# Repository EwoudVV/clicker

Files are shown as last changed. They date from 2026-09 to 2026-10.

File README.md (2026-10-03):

# Clicker

A 2-switch wireless macropad.

This project is 2 pcbs. One is a reciever, which you plug into your computer, and the other is a remote, or transmitter, with the buttons. The reciever acts like a keyboard, so no drivers need to be installed on the computer.



Remote: 
Receiver: 

Reciever pcb:
 - 2 layer
 - esp32 s3
 - has a usb-c port for computer
 - an led that blinks when something is being sent

Remote pcb:
 - same esp32 s3
 - small battery
 - 2 switches (khalih choc v1 smd)
 - 2 layer
 - 2 side assembly
 - usb-c port for charging

Roadmap:
 - finish up, make production files
 - submit!

Completed:
 - Find and place symbols
 - wire up both schematics
 - find specific part numbers and footprints for everything
 - route the pcbs

Designed by EVV

*Made for Hack Club Half Life*

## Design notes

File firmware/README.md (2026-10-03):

# Clicker firmware

The remote sends its two button states over ESP-NOW. The receiver turns them into USB keyboard reports. Button 1 is left arrow and button 2 is right arrow by default, for slides.

Both sketches compile with Espressif's Arduino core 3.3.12. The boards have not been built or tested yet.

## boards and pins

| | remote | receiver |
|---|---|---|
| module | ESP32-C3-WROOM-02-N4 | ESP32-S3-WROOM-1-N4 |
| button 1 | GPIO5, active low | — |
| button 2 | GPIO6, active low | — |
| LED | GPIO7, active high | GPIO4, active high |
| USB D-/D+ | GPIO18 / GPIO19 | GPIO19 / GPIO20 |
| debug RX / TX | GPIO20 / GPIO21 | GPIO44 / GPIO43 |

These are GPIO numbers, not the module's physical pad numbers. They come from the schematics. The battery divider is on remote GPIO4; this version does not use it for battery protection or sleep.

## build

Install Arduino CLI and the official ESP32 core:

```sh
arduino-cli core update-index --additional-urls https://espressif.github.io/arduino-esp32/package_esp32_index.json
arduino-cli core install esp32:esp32@3.3.12 --additional-urls https://espressif.github.io/arduino-esp32/package_esp32_index.json
```

From the repo root:

```sh
./firmware/test.sh
./firmware/build.sh
```

`test.sh` runs the portable button/packet state tests on the computer, with address and undefined-behavior sanitizers. It does not emulate Wi-Fi, USB, flash storage, or the electronics. `build.sh` compiles both sketches and saves compiler results under `verification/2026-10-03/`. Builds go in the ignored `work/` folder.

In Arduino IDE, add `firmware/libraries` as a sketchbook library location or install its Clicker folder as a library. Select **ESP32C3 Dev Module** for the remote and **ESP32S3 Dev Module** for the receiver, with 4 MB flash, no PSRAM, and USB CDC on boot enabled. The receiver needs **USB-OTG (TinyUSB)** USB mode. Hardware CDC/JTAG mode cannot provide the keyboard interface.

For the first flash, hold BOOT, tap RESET, then release BOOT and select the board's serial port. Both boards have USB wired to the native pins. If that does not enumerate, use the debug header with a 3.3 V logic USB-UART adapter. The header is GND, RX, TX; it has no power pin. UART lines cross: adapter TX to board RX and adapter RX to board TX. Power the board through USB.

From the `firmware` folder, replacing `<port>` with the real port:

```sh
arduino-cli upload --fqbn esp32:esp32:esp32c3:CDCOnBoot=cdc,FlashSize=4M --input-dir ../work/build-remote --port '<port>' remote
arduino-cli upload --fqbn esp32:esp32:esp32s3:USBMode=default,CDCOnBoot=cdc,FlashSize=4M,PSRAM=disabled --input-dir ../work/build-receiver --port '<port>' receiver
```

These upload steps are instructions for later; no board has been flashed.

## pairing

Each board has a USB serial configuration console at 115200 baud. Send commands with a newline. Nothing transmits keyboard data until the pair is configured.

1. Run `status` on each board and note its MAC address.
2. Generate one random 16-byte link key on your computer:

   ```sh
   python3 -c 'import secrets; print(secrets.token_hex(16))'
   ```

3. On the remote, send `pair <receiver-MAC> <key>`.
4. On the receiver, send `pair <remote-MAC> <same-key>`.

For example, the command shape is `pair AA:BB:CC:DD:EE:02 <32 hex digits>`; use the actual other board's address and the generated key. Pairing survives restarts. `unpair` removes it. `status` shows addresses and mappings but does not print the key.

Both devices use Wi-Fi channel 1 and encrypted unicast ESP-NOW. No router or Wi-Fi password is needed. The receiver also checks that packets came from the configured remote address. If changing the radio channel in the source, rebuild both boards.

## remapping

Send these commands to the receiver's USB serial console. They save in flash immediately, with no new firmware upload needed:

```text
map 1 left
map 2 right
status
```

For page up/down:

```text
map 1 pageup
map 2 pagedown
```

Other names: `up`, `down`, `space`, `enter`, `escape`, `home`, `end`, `a` through `z`, or `disabled`. For other keys, use a USB HID keyboard usage number, such as `0x3A` for F1. These are HID usages, not ASCII or Arduino `KEY_*` values. Supported numeric usages are 0x04 through 0x65.

An optional modifier byte supports shortcuts:

```text
map 1 a 0x08
map 2 b 0x02
```

That maps button 1 to Command+A on macOS, and button 2 to Shift+B. Modifier bits are left Ctrl 0x01, Shift 0x02, Alt/Option 0x04, GUI/Command 0x08; right-side equivalents are 0x10, 0x20, 0x40, 0x80. Add the bits for combinations. Media consumer-control usages and multi-step macros are not implemented.

Open the serial console again and use `status` if the boot message was missed. On macOS a terminal console can be opened with `screen <serial-port> 115200`; leave it with Ctrl+A, then K. Close the console before uploading firmware.

## behavior

- Button debounce is 15 ms.
- Full state packets go out on changes and every 50 ms. A later packet can recover a dropped release.
- The receiver drops duplicate and older sequence numbers within a remote boot session.
- After 300 ms without a valid new packet, the receiver releases all keys.
- Both pressed buttons appear together in one HID report. Identical mappings appear once.
- Failed USB reports are retried; a USB reconnect sends the current state again.
- The remote LED indicates a queued send, not a delivery acknowledgement. The receiver LED flashes on accepted packets.

This version keeps the remote's radio awake. Battery runtime and low-power sleep need measurements before choosing a power-saving strategy.

## when the boards arrive

- Check assembly, connector polarity, and resistance between power and ground before powering.
- Start with current-limited USB power and measure both 3.3 V rails. Address the open power issues in `docs/hardware-review-2026-10-03.md` before connecting a battery.
- Flash each board, open its console, and check `status`.
- Pair the devices. Verify the receiver appears as a keyboard and serial device.
- Test short presses, holds, and both buttons in a text editor, then in slides.
- Hold a button and turn the remote off. Confirm the computer releases the key within about 300 ms.
- Change mappings, restart both boards, and verify the saved settings.
- Disconnect/reconnect the receiver USB while a button is held. Verify there are no stuck keys.
- Measure battery supply sag and current during transmission. Check charging and charge termination with the selected battery and both switch positions.
- Check range and latency with the final case and battery in place.

References: [Arduino ESP-NOW](https://docs.espressif.com/projects/arduino-esp32/en/latest/api/espnow.html), [Arduino USB](https://docs.espressif.com/projects/arduino-esp32/en/latest/api/usb.html), [Espressif USB keyboard source](https://github.com/espressif/arduino-esp32/blob/3.3.12/libraries/USB/src/USBHIDKeyboard.cpp).

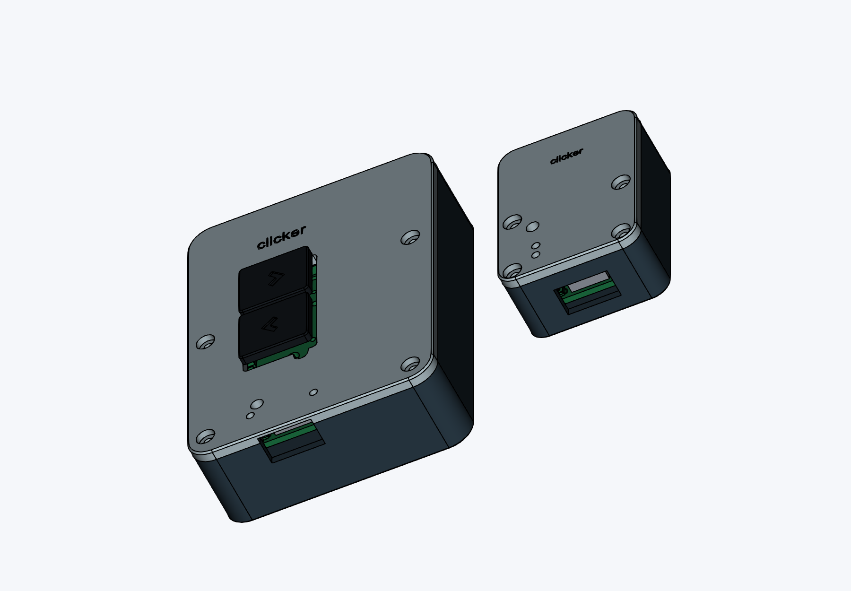
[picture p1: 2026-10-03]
enclosures/preview.png

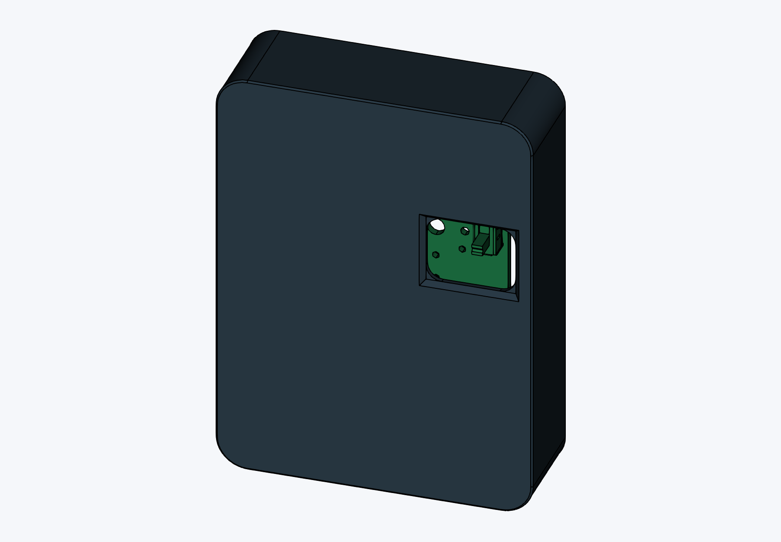
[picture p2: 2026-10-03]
enclosures/remote-underside.png

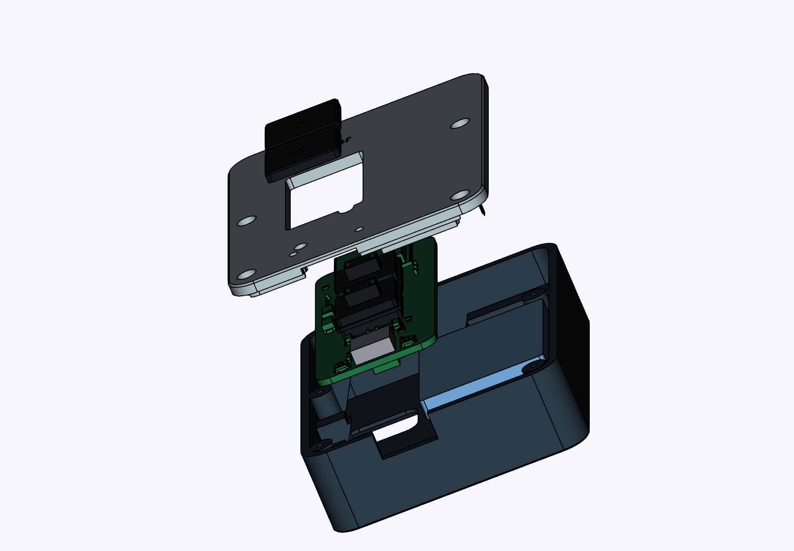
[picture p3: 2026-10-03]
enclosures/remote-exploded.png

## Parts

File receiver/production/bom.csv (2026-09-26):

Item # | Designator | Qty | Manufacturer | Mfg Part # | Description | Package | Type
1 | U1 | 1 | Espressif | ESP32-S3-WROOM-1-N4 | WiFi+BLE5 module, 4MB flash, PCB antenna, native USB | SMD module | Module
2 | U2 | 1 | Diodes Inc | AP2112K-3.3TRG1 | 600mA low-dropout regulator, 3.3V fixed | SOT-23-5 | IC
3 | J1 | 1 | HRO | TYPE-C-31-M-12 | USB Type-C receptacle, 16P, USB2.0+PD | SMD | Connector
4 | HDR1 | 1 | Generic | 1x03 2.54mm pin header | Pin header 1x3, 2.54mm pitch, vertical | THT | Connector
5 | SW_BOOT, SW_RST | 2 | Omron | B3U-1000P | Tactile switch, top actuated | SMD | Switch
6 | D1 | 1 | Everlight | 19-213/R6C-AL1M2VY/3T | Red 0603 LED | 0603 | LED
7 | R_ACT | 1 | UNI-ROYAL | 0603WAF1001T5E | 1k ohm 1% 1/10W | 0603 | Resistor
8 | R_CC1, R_CC2 | 2 | UNI-ROYAL | 0603WAF5101T5E | 5.1k ohm 1% 1/10W | 0603 | Resistor
9 | R_EN | 1 | UNI-ROYAL | 0603WAF1002T5E | 10k ohm 1% 1/10W | 0603 | Resistor
10 | C1 | 1 | Samsung | CL10B104KB8NNNC | 100nF 50V X7R ceramic | 0603 | Capacitor
11 | C2 | 1 | Samsung | CL10A106MQ8NNNC | 10uF 6.3V X5R ceramic | 0603 | Capacitor
12 | C3 | 1 | Samsung | CL10B105KO8NNNC | 1uF 25V X7R ceramic | 0603 | Capacitor

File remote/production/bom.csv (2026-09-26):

Item # | Designator | Qty | Manufacturer | Mfg Part # | Description | Package | Type
1 | U1 | 1 | Espressif | ESP32-C3-WROOM-02-N4 | WiFi+BLE5 module, RISC-V, 4MB flash, PCB antenna | SMD module | Module
2 | U2 | 1 | Microchip | MCP73831T-2ATI/OT | Li-Ion charge management controller, 4.2V, 500mA | SOT-23-5 | IC
3 | U3 | 1 | Diodes Inc | AP2112K-3.3TRG1 | 600mA low-dropout regulator, 3.3V fixed | SOT-23-5 | IC
4 | J1 | 1 | HRO | TYPE-C-31-M-12 | USB Type-C receptacle, 16P, USB2.0+PD | SMD | Connector
5 | J_BAT | 1 | JST | B2B-PH-K-S | PH 2.0mm 2-pin vertical header | THT | Connector
6 | HDR1 | 1 | Generic | 1x03 2.54mm pin header | Pin header 1x3, 2.54mm pitch, vertical | THT | Connector
7 | SW1, SW2 | 2 | Kailh | CPG135001D01 | Choc V1 low-profile mechanical switch, linear red | THT | Switch
8 | SW_BOOT, SW_RST | 2 | Omron | B3U-1000P | Tactile switch, top actuated | SMD | Switch
9 | SW_PWR | 1 | C&K | OS102011MS2Q | Miniature SPDT slide switch | THT | Switch
10 | D_CHG, D_STAT | 2 | Everlight | 19-213/R6C-AL1M2VY/3T | Red 0603 LED | 0603 | LED
11 | D_VBAT, D_VBUS | 2 | MDD | SS14 | 1A 40V Schottky rectifier | SMA | Diode
12 | R_CC1, R_CC2 | 2 | UNI-ROYAL | 0603WAF5101T5E | 5.1k ohm 1% 1/10W | 0603 | Resistor
13 | R_EN | 1 | UNI-ROYAL | 0603WAF1002T5E | 10k ohm 1% 1/10W | 0603 | Resistor
14 | R_UP, R_DN | 2 | UNI-ROYAL | 0603WAF1003T5E | 100k ohm 1% 1/10W | 0603 | Resistor
15 | R_PROG | 1 | UNI-ROYAL | 0603WAF2001T5E | 2k ohm 1% 1/10W | 0603 | Resistor
16 | R_CHG, R_STAT | 2 | UNI-ROYAL | 0603WAF1001T5E | 1k ohm 1% 1/10W | 0603 | Resistor
17 | C1 | 1 | Samsung | CL10B104KB8NNNC | 100nF 50V X7R ceramic | 0603 | Capacitor
18 | C2 | 1 | Samsung | CL10A106MQ8NNNC | 10uF 6.3V X5R ceramic | 0603 | Capacitor
19 | C3 | 1 | Samsung | CL10B105KO8NNNC | 1uF 25V X7R ceramic | 0603 | Capacitor

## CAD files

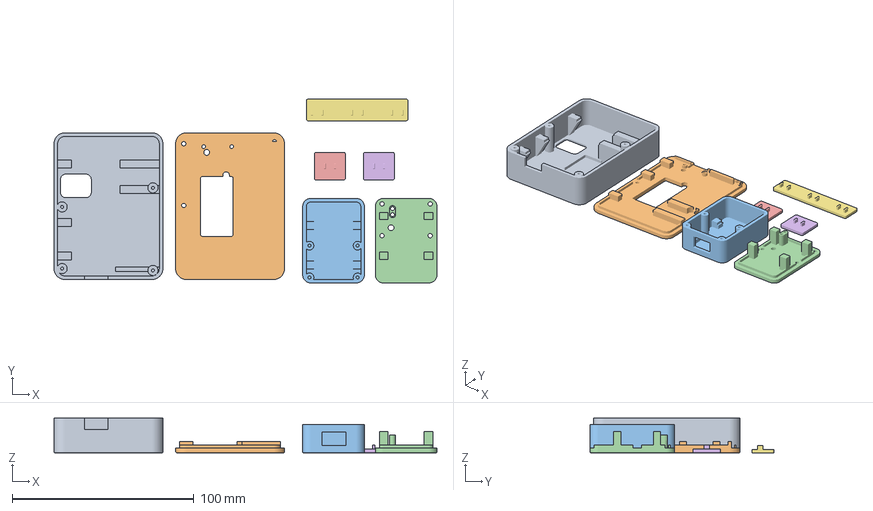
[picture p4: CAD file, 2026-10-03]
enclosures/clicker-print-plate.3mf
211.0 x 101.3 x 19.1 mm
remote_base
remote_lid
receiver_base
receiver_lid
keycap_previous
keycap_next
stem_fit_coupon

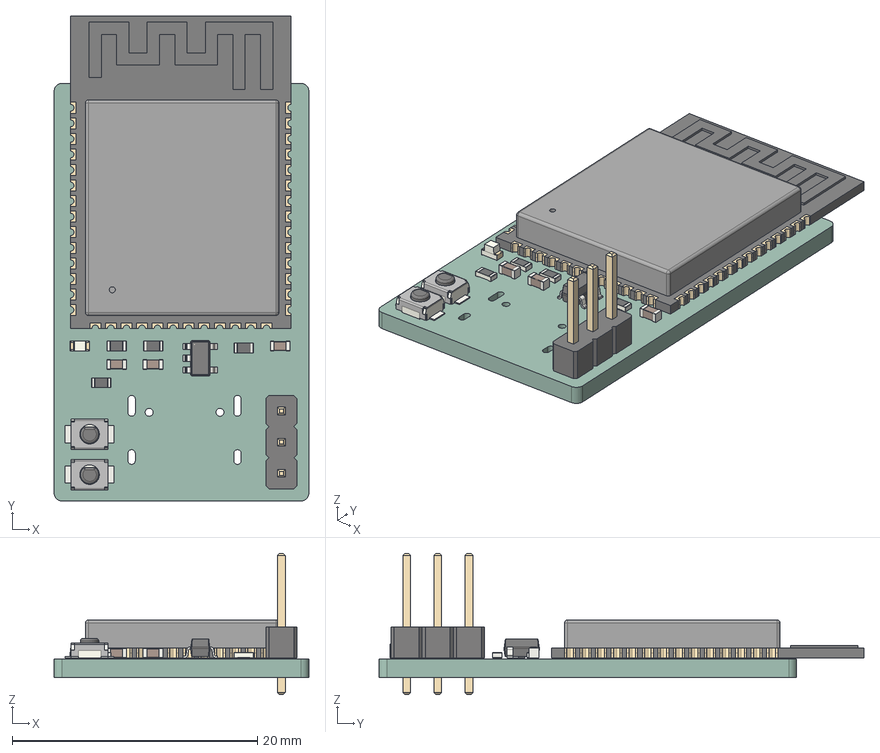
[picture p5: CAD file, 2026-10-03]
enclosures/reference/receiver.step
20.8 x 39.6 x 11.5 mm
R_0603_1608Metric x 4
C_0603_1608Metric x 3
SW_SPST_B3U-1000P x 2
PinHeader_1x03_P254mm_Vertical
LED_0603_1608Metric
ESP32-S3-WROOM-1
SOT-23-5
receiver_PCB

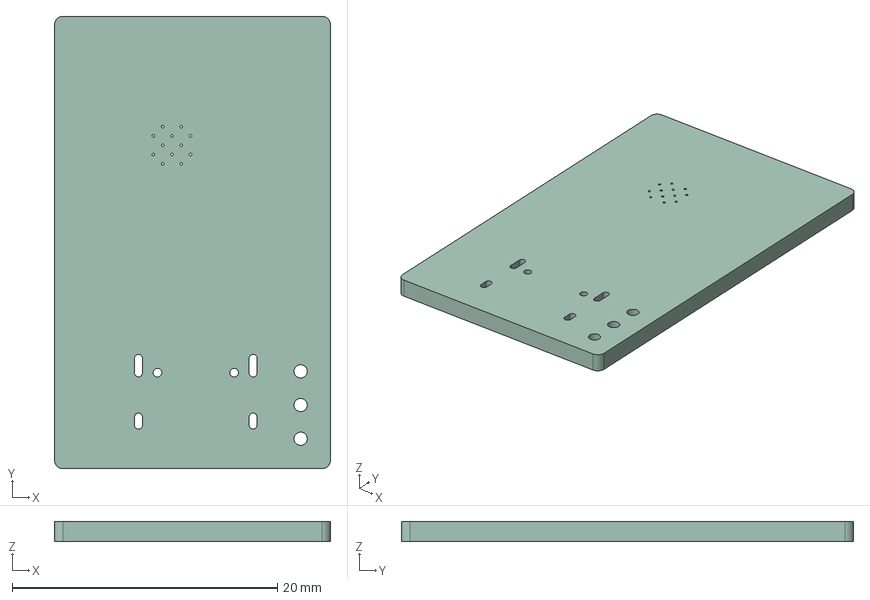
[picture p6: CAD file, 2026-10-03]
enclosures/reference/receiver-board.step
20.8 x 34.1 x 1.51 mm

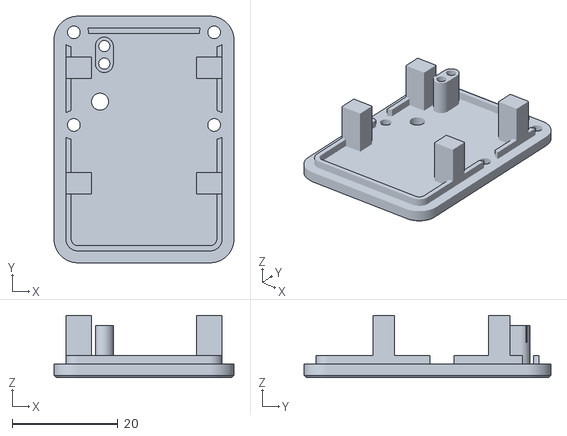
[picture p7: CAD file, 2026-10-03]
enclosures/stl/receiver_lid.stl
34.0 x 46.6 x 11.8

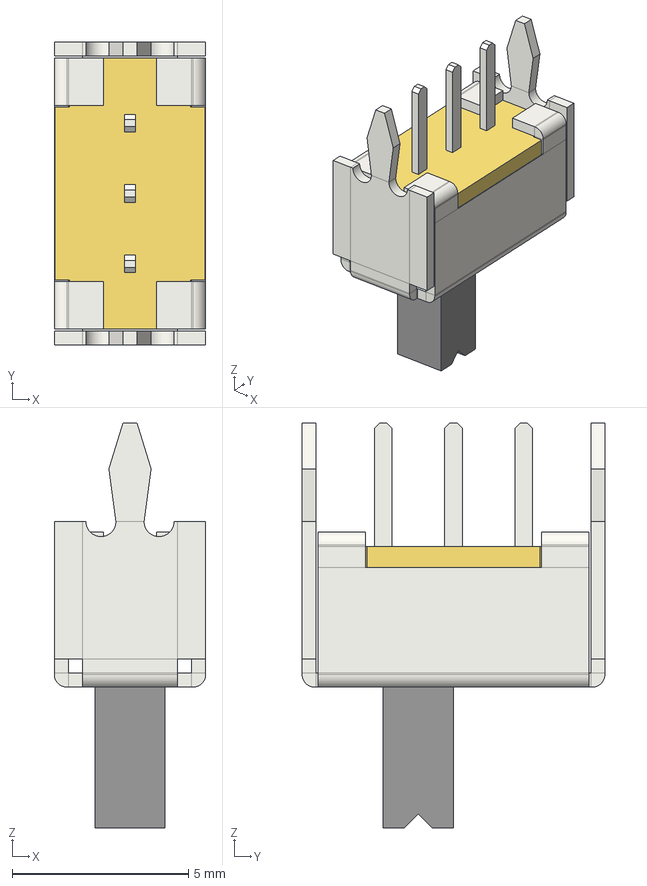
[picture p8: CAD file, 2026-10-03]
enclosures/reference/power_switch.step
4.30 x 8.60 x 11.5 mm

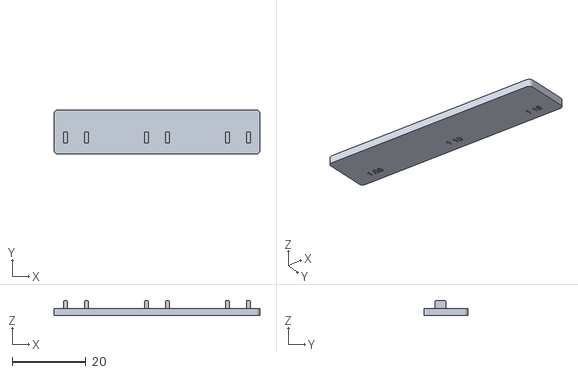
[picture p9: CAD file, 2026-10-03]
enclosures/stl/stem_fit_coupon.stl
56.0 x 12.0 x 4.00

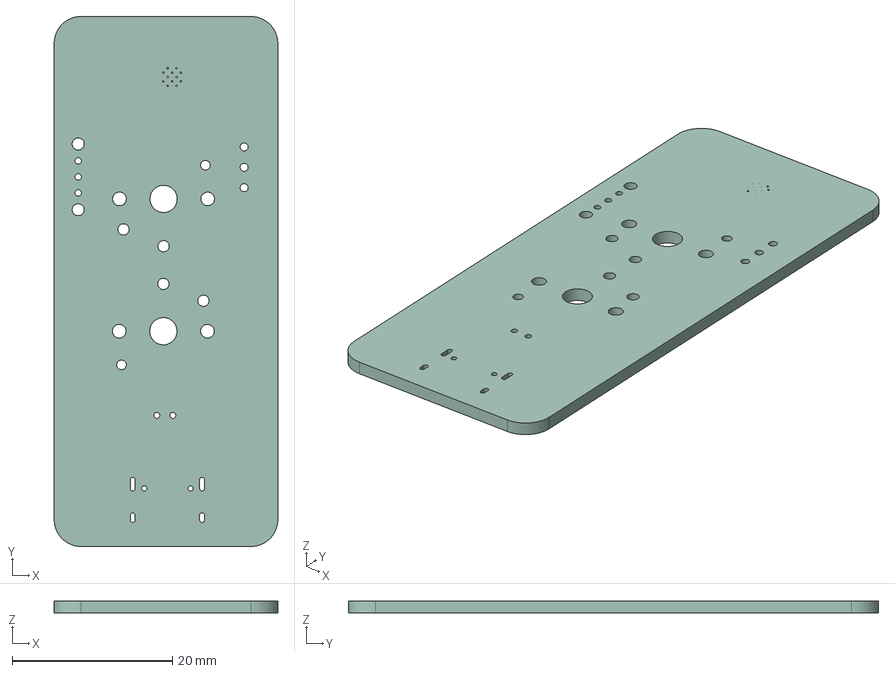
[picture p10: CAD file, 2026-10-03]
enclosures/reference/remote-board.step
27.9 x 66.1 x 1.51 mm

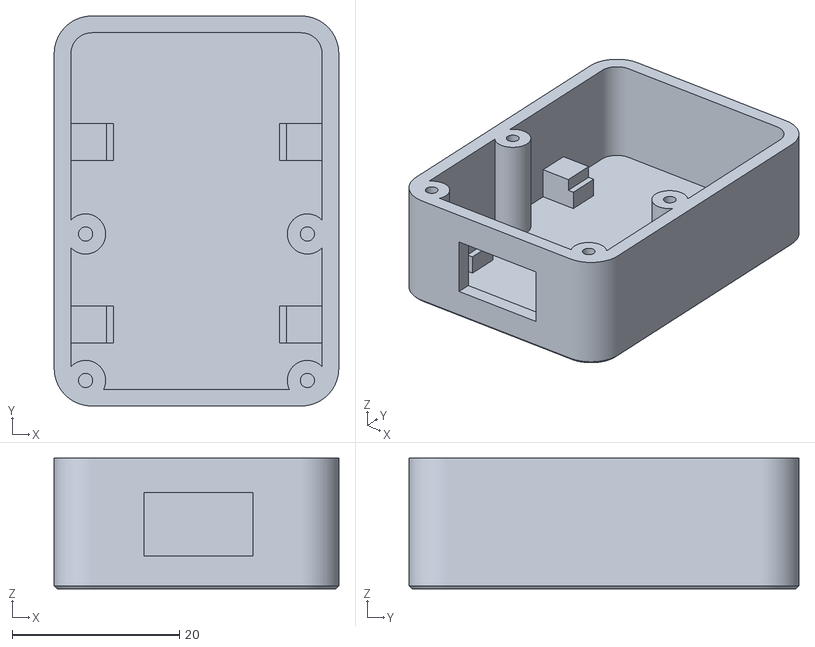
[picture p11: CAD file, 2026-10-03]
enclosures/stl/receiver_base.stl
34.0 x 46.6 x 15.6

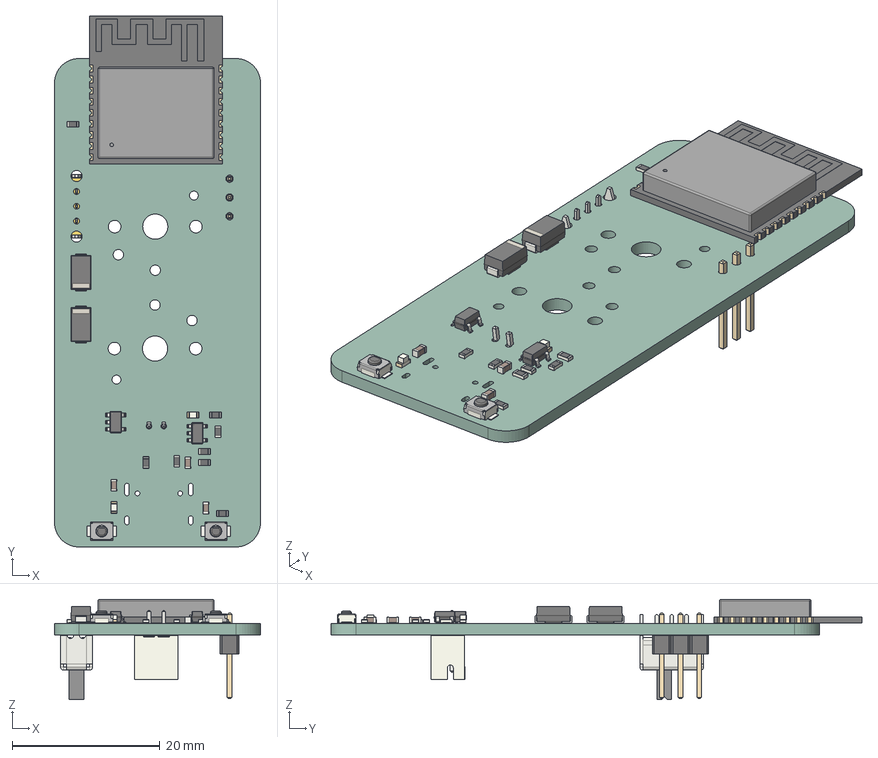
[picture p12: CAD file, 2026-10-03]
enclosures/reference/remote.step
27.9 x 71.8 x 13.6 mm
R_0603_1608Metric x 8
LED_0603_1608Metric x 2
SW_SPST_B3U-1000P x 2
D_SMA x 2
C_0603_1608Metric x 3
SOT-23-5 x 2
ESP32-C3-WROOM-02
PinHeader_1x03_P254mm_Vertical
JST_B2B_PH_K
SW_Slide_SPDT_Straight_CK_OS102011MS2Q
remote_PCB

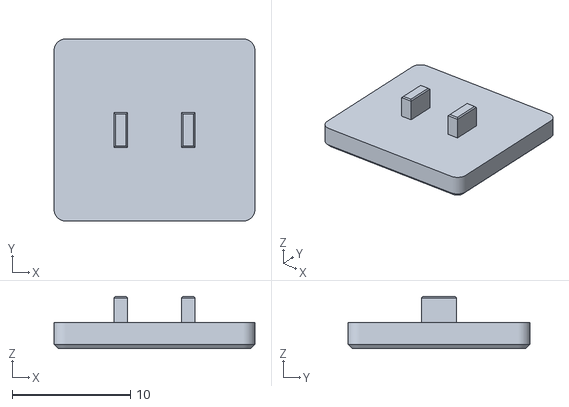
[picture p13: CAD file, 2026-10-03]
enclosures/stl/keycap_next.stl
17.0 x 15.4 x 4.40

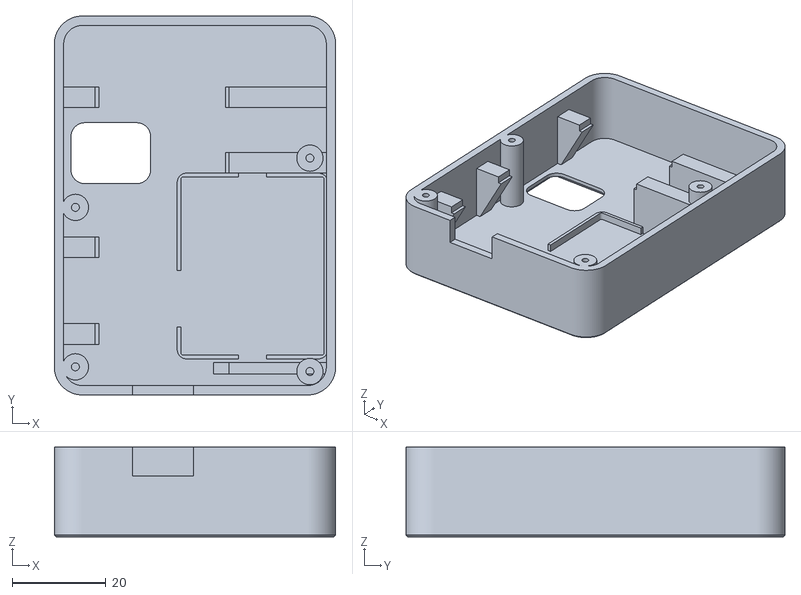
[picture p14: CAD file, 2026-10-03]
enclosures/stl/remote_base.stl
60.0 x 80.8 x 19.1

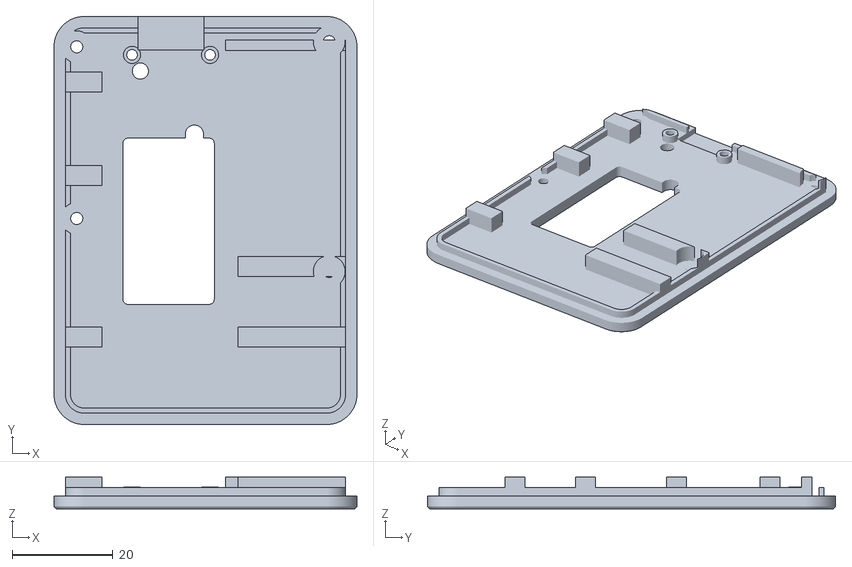
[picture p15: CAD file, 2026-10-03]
enclosures/stl/remote_lid.stl
60.0 x 80.8 x 6.30

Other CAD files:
enclosures/stl/keycap_previous.stl

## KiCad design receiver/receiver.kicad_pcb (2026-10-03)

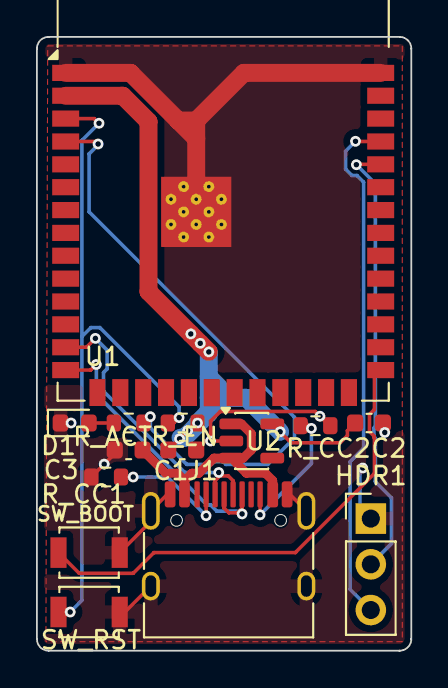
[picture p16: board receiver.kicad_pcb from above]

Board: 2 copper layers, 20.8 x 34.1 mm, 14 parts (0 on the bottom side), 13 nets.

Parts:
C1: 100nF; C_0603_1608Metric
C2: 10uF; C_0603_1608Metric
C3: 1uF; C_0603_1608Metric
D1: ACT; LED_0603_1608Metric
HDR1: DEBUG; PinHeader_1x03_P2.54mm_Vertical
J1: USB-C; USB_C_Receptacle_HRO_TYPE-C-31-M-12
R_ACT: 1k; R_0603_1608Metric
R_CC1, R_CC2: 5.1k; R_0603_1608Metric
R_EN: 10k; R_0603_1608Metric
SW_BOOT: BOOT; SW_SPST_B3U-1000P
SW_RST: RESET; SW_SPST_B3U-1000P
U1: ESP32-S3-WROOM-1
U2: AP2112K-3.3; SOT-23-5

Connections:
3v3: C1.1, C2.1, R_EN.2, U1.2, U2.5
ACT_A: D1.2, R_ACT.2
BOOT_NET: SW_BOOT.1, U1.27
CC1: J1.A5, R_CC1.1
CC2: J1.B5, R_CC2.1
EN_NET: R_EN.1, SW_RST.1, U1.3
GND: C1.2, C2.2, C3.2, D1.1, HDR1.1, J1.A1, J1.A12, J1.B1, J1.B12, J1.SH, R_CC1.2, R_CC2.2, SW_BOOT.2, SW_RST.2, U1.1, U1.40, U1.41, U2.2
LED_ACT: R_ACT.1, U1.4
UART_RX: HDR1.2, U1.36
UART_TX: HDR1.3, U1.37
USB_DN: J1.A7, J1.B7, U1.13
USB_DP: J1.A6, J1.B6, U1.14
VBUS: C3.1, J1.A4, J1.A9, J1.B4, J1.B9, U2.1, U2.3

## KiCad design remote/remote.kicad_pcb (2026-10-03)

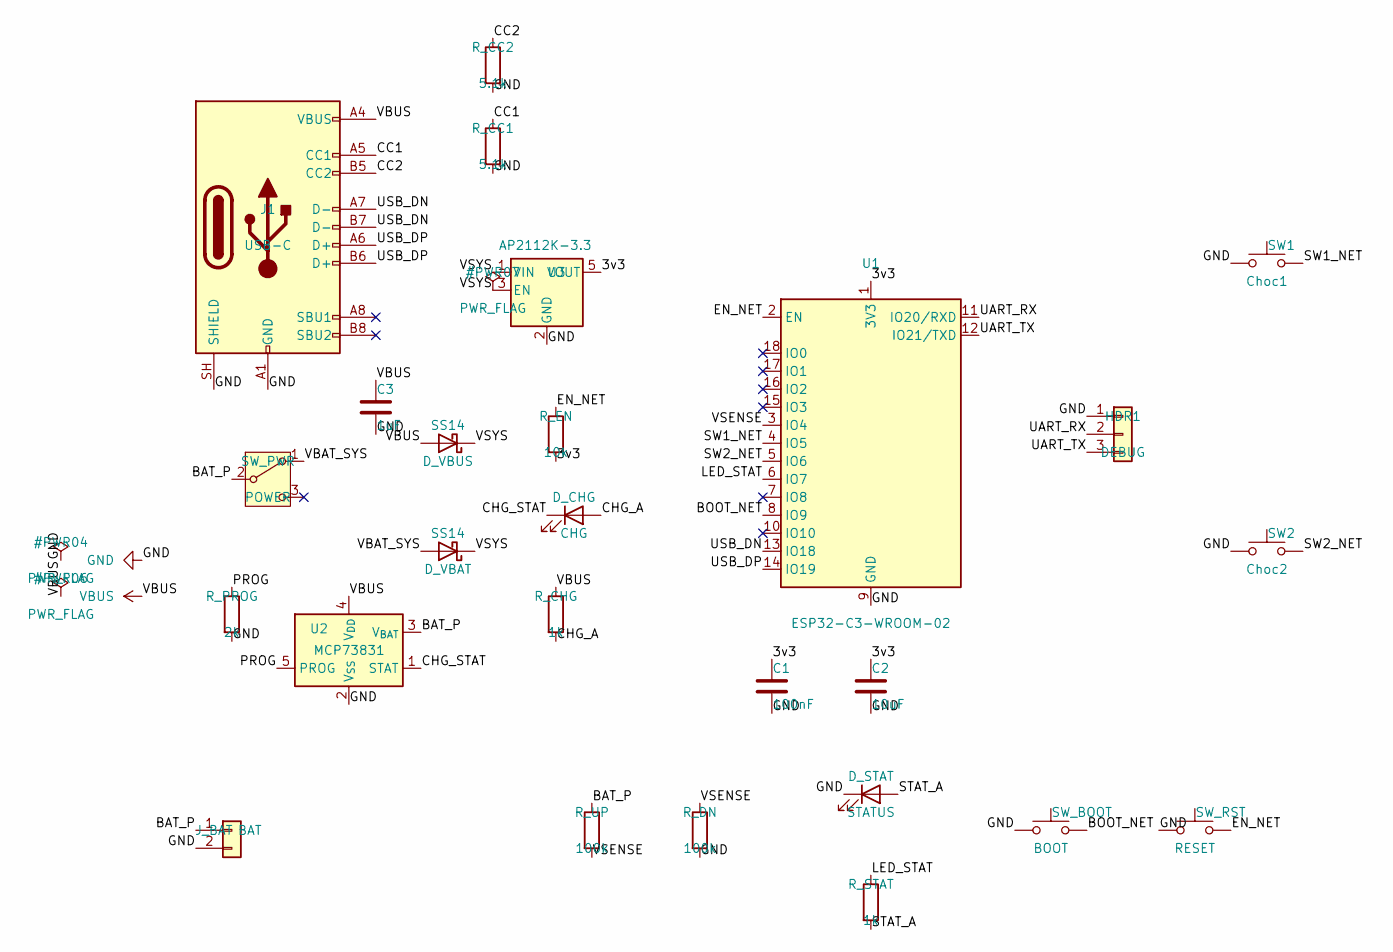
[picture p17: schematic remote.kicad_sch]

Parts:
C1: 100nF; C_0603_1608Metric
C2: 10uF; C_0603_1608Metric
C3: 1uF; C_0603_1608Metric
D_CHG: CHG; LED_0603_1608Metric
D_STAT: STATUS; LED_0603_1608Metric
D_VBAT: SS14; D_SMA
D_VBUS: SS14; D_SMA
HDR1: DEBUG; PinHeader_1x03_P2.54mm_Vertical
J1: USB-C; USB_C_Receptacle_HRO_TYPE-C-31-M-12
J_BAT: BAT; JST_PH_B2B-PH-K_1x02_P2.00mm_Vertical
R_CC1, R_CC2: 5.1k; R_0603_1608Metric
R_CHG: 1k; R_0603_1608Metric
R_DN: 100k; R_0603_1608Metric
R_EN: 10k; R_0603_1608Metric
R_PROG: 2k; R_0603_1608Metric
R_STAT: 1k; R_0603_1608Metric
R_UP: 100k; R_0603_1608Metric
SW1: Choc1; Choc_V1_PG1350
SW2: Choc2; Choc_V1_PG1350
SW_BOOT: BOOT; SW_SPST_B3U-1000P
SW_PWR: POWER; SW_Slide_SPDT_Straight_CK_OS102011MS2Q
SW_RST: RESET; SW_SPST_B3U-1000P
U1: ESP32-C3-WROOM-02
U2: MCP73831; SOT-23-5
U3: AP2112K-3.3; SOT-23-5

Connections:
3v3: C1.1, C2.1, R_EN.2, U1.1 (3V3), U3.5 (VOUT)
BAT_P: J_BAT.1, R_UP.1, SW_PWR.2 (B), U2.3 (V_{BAT})
BOOT_NET: SW_BOOT.2, U1.8 (IO9)
CC1: J1.A5 (CC1), R_CC1.1
CC2: J1.B5 (CC2), R_CC2.1
CHG_A: D_CHG.2 (A), R_CHG.2
CHG_STAT: D_CHG.1 (K), U2.1 (STAT)
EN_NET: R_EN.1, SW_RST.2, U1.2 (EN)
LED_STAT: R_STAT.1, U1.6 (IO7)
PROG: R_PROG.1, U2.5 (PROG)
STAT_A: D_STAT.2 (A), R_STAT.2
SW1_NET: SW1.2, U1.4 (IO5)
SW2_NET: SW2.2, U1.5 (IO6)
UART_RX: HDR1.2, U1.11 (IO20/RXD)
UART_TX: HDR1.3, U1.12 (IO21/TXD)
USB_DN: J1.A7 (D-), J1.B7 (D-), U1.13 (IO18)
USB_DP: J1.A6 (D+), J1.B6 (D+), U1.14 (IO19)
VBAT_SYS: D_VBAT.2 (A), SW_PWR.1 (A)
VSENSE: R_DN.1, R_UP.2, U1.3 (IO4)

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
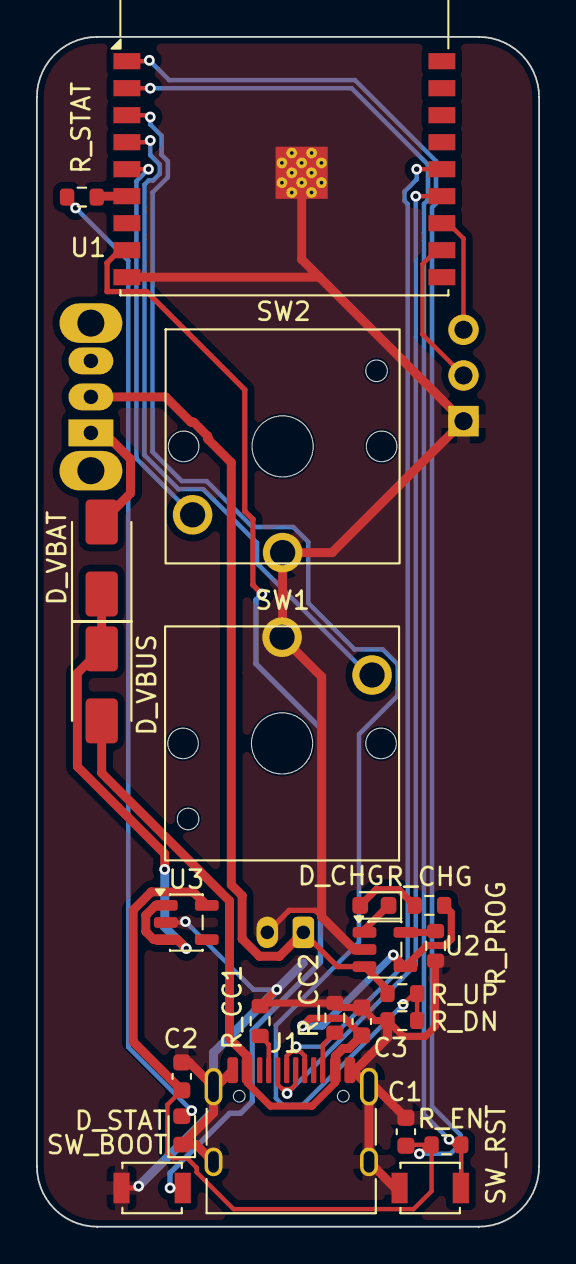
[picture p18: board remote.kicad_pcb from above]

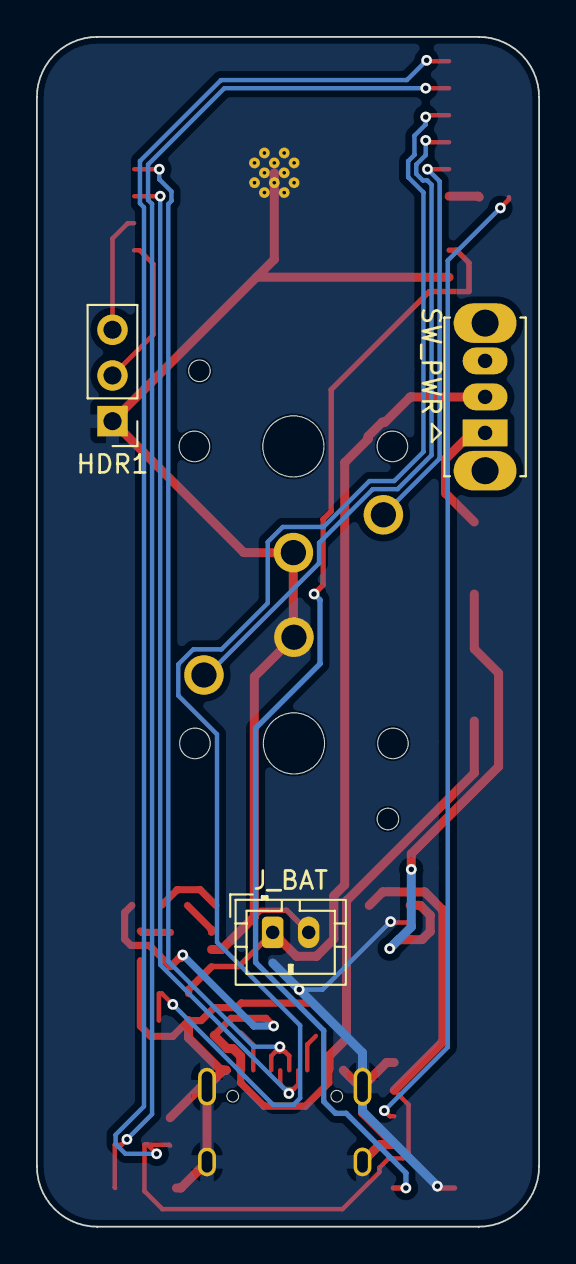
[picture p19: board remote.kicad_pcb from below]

Board: 2 copper layers, 27.9 x 66.1 mm, 26 parts (3 on the bottom side), 22 nets.

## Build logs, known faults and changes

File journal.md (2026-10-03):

# Journal

devlogs for progress

### Devlog 01

Date: Sep 19
Time spent: 1 hour
Lapse: No lapse

Initialized the repo, git, created the 2 kicad projects, created the project structure, wrote up a readme.

### Devlog 02

Date: Sep 20
Time spent: 30 minutes
Lapse: [lapse](https://lapse.hackclub.com/timelapse/JvdpDzcCZuD7)

Finished the remote schematic.
Placed the schematic symbols and wired everything up with labels.

### Devlog 03

Date: Sep 20
Time spent: 30 minutes
Lapse: [lapse](https://lapse.hackclub.com/timelapse/a2XuRAxTbL4d)

Finished the reciever schematic.
Placed the schematic symbols and wired everything up with labels.
Also fixed something from the remote schematics: the schottky diodes were backwards.
I also had to add power flags for both schematics, which i forgot about.

### Devlog 04

Date: Sep 20
Time spent: 1 hour
Lapse: [lapse](https://lapse.hackclub.com/timelapse/9pbpZWGdKg2V)

i found exact part numbers i needed for each symbol, and assigned all of them footprints, and updated both pcbs from both schematics. i routed the reciever pcb, but there are 200 errors that i have to work through, most of them are clearance violations that are probably fine and will go away once i adjust stuff.
i had to make my own footprint for the switch btw

### Devlog 05

Date: Sep 20
Time spent: 1 hour
Lapse: no lapse

i found the errors:
root causes all mechanical: tight outline, strict hole rule, one redundant via
expanded outline, corrected hole rule to fab capability, removed via
result: zero blocking errors, thermals stuff accepted, doing silkscreen cleanup now

### Devlog 06

Date: Sep 22
Time Spent: 30 minutes
Lapse: [lapse](https://lapse.hackclub.com/timelapse/fsMvkNjTQimd)

routed the remote board!
also added edge.cuts outline with rounded edges, cleaned up silkscreen, flipped some tht components to the back like the switch, debug header, and batt connector

### Devlog 07

Date: Sep 26
Time Spent: 1 hour
Lapse: no lapse

fixed a short in the remote board, make all production files, sourced parts for the boms

### Devlog 08

Date: Oct 3
Time Spent: 2 hours
Lapse: no lapse

made firmware for both boards: slide arrows by default, saved key remapping over USB, and configurable encrypted pairing.
both scripts compile
Fixed five thermal errors and the remot’s ERC error. Both PCBs now have zero DRC errors and unrouted connections, warnings are still there
refreshed Gerbers and wrote setup instructions

### Devlog 09

Date: Oct 3
Time Spent: 2 hours
Lapse: no lapse

I sourced exact links and prices for each part of the project. i tried to optimize it for cost, but it is ~$30 over budget. I can try to pay for the rest myself, but.. im kinda broke. Ill see if i can scrounge together some coupons before i order.

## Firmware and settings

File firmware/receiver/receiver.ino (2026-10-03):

#include <Clicker.h>
#include <USB.h>
#include <USBHIDKeyboard.h>
#include <freertos/FreeRTOS.h>
#include <freertos/queue.h>

#if !CONFIG_IDF_TARGET_ESP32S3 || ARDUINO_USB_MODE != 0
#error "Build for ESP32-S3 with USB-OTG (TinyUSB), not hardware JTAG/CDC."
#endif

constexpr uint8_t kLed = 4;
USBHIDKeyboard keyboard;
USBHID hid;
clicker::Device device;
clicker::ReceiverState state;
struct Incoming { uint8_t source[6]; clicker::Packet packet; };
QueueHandle_t incoming;
hid_keyboard_report_t appliedReport{};
bool reportApplied = false;
bool wasUsbReady = false;
uint32_t ledUntil = 0;

void receive(const esp_now_recv_info_t *info, const uint8_t *data, int length) {
  if (!info || length != sizeof(clicker::Packet)) return;
  Incoming item;
  memcpy(item.source, info->src_addr, 6);
  memcpy(&item.packet, data, sizeof(item.packet));
  // ESP-NOW runs this on the Wi-Fi task. USB and settings stay in loop().
  xQueueSend(incoming, &item, 0);
}

bool applyButtons(uint8_t mask) {
  hid_keyboard_report_t report{};
  unsigned count = 0;
  for (int i = 0; i < 2; ++i) {
    uint8_t usage = device.settings.usage[i];
    if (!(mask & (1 << i)) || !usage) continue;
    report.modifier |= device.settings.modifiers[i];
    if (count == 0 || report.keycode[0] != usage) report.keycode[count++] = usage;
  }
  if (reportApplied && memcmp(&report, &appliedReport, sizeof(report)) == 0) return true;
  if (!hid.SendReport(HID_REPORT_ID_KEYBOARD, &report, sizeof(report), 10)) return false;
  appliedReport = report;
  reportApplied = true;
  return true;
}

void setup() {
  Serial.begin(115200);
  pinMode(kLed, OUTPUT);
  digitalWrite(kLed, LOW);
  incoming = xQueueCreate(16, sizeof(Incoming));
  if (!incoming) { Serial.println("Receive queue failed."); return; }
  keyboard.begin();
  USB.productName("Clicker");
  USB.begin();
  device.begin("clicker-recv");
  if (device.radioReady && esp_now_register_recv_cb(receive) != ESP_OK)
    Serial.println("Receive callback failed.");
  device.status();
}

void loop() {
  if (!incoming) { delay(100); return; }
  if (device.pollConsole(true)) {
    state.reset();
    reportApplied = false;
    xQueueReset(incoming);
  }
  Incoming item;
  uint32_t now = millis();
  while (xQueueReceive(incoming, &item, 0) == pdTRUE) {
    if (device.isPeer(item.source) && state.accept(item.packet, now)) ledUntil = now + 8;
  }
  state.expire(now);
  // Reapply after USB reconnect; release keys after a radio timeout.
  bool ready = hid.ready();
  if (!ready || !wasUsbReady) reportApplied = false;
  if (ready) applyButtons(state.buttons);
  wasUsbReady = ready;
  digitalWrite(kLed, int32_t(ledUntil - now) > 0 ? HIGH : LOW);
  delay(1);
}

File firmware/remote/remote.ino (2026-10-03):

#include <Clicker.h>
#include <esp_random.h>

#if !CONFIG_IDF_TARGET_ESP32C3
#error "Build the remote for ESP32-C3."
#endif

constexpr uint8_t kButtons[2] = {5, 6};
constexpr uint8_t kLed = 7;
clicker::Device device;
clicker::Debouncer buttons[2];
uint32_t session, sequence = 0, lastSent = 0, ledUntil = 0;
uint8_t lastMask = 0xff;

void setup() {
  Serial.begin(115200);
  for (auto pin : kButtons) pinMode(pin, INPUT_PULLUP);
  pinMode(kLed, OUTPUT);
  digitalWrite(kLed, LOW);
  device.begin("clicker-remote");
  session = esp_random();
  device.status();
}

void loop() {
  if (device.pollConsole(false)) lastMask = 0xff;
  uint32_t now = millis();
  uint8_t mask = 0;
  for (int i = 0; i < 2; ++i) {
    buttons[i].update(digitalRead(kButtons[i]) == LOW, now);
    if (buttons[i].pressed) mask |= 1 << i;
  }
  if (device.canSend() && (mask != lastMask || uint32_t(now - lastSent) >= clicker::kHeartbeatMs)) {
    clicker::Packet packet{clicker::kMagic, session, ++sequence, 1, mask, 0};
    if (esp_now_send(device.settings.peer, reinterpret_cast<uint8_t *>(&packet), sizeof(packet)) == ESP_OK) {
      lastMask = mask;
      ledUntil = now + 8;
    }
    lastSent = now;
  }
  // This indicates a queued transmission, not confirmation that the receiver got it.
  digitalWrite(kLed, int32_t(ledUntil - now) > 0 ? HIGH : LOW);
  delay(1);
}

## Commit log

2026-09-19 devlog 01
    [receiver.kicad_pcb, receiver.kicad_sch, remote.kicad_pcb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]
2026-09-20 devlog 02
    [receiver.kicad_sch, remote.kicad_sch]
2026-09-20 devlog 03
    [receiver.kicad_sch, remote.kicad_sch]
2026-09-20 fix stuff
    [receiver.kicad_sch, remote.kicad_sch]
2026-09-20 devlog 04
    [receiver.kicad_pcb, receiver.kicad_sch, remote.kicad_pcb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]
2026-09-20 devlog 05
    [receiver.kicad_pcb]
2026-09-22 devlog 06
    [receiver.kicad_pcb, remote.kicad_pcb]
2026-09-26 devlog 07
    [bom.csv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]
2026-10-03 devlog 08
    [receiver-B_Cu.gbl, receiver-B_Mask.gbs, receiver-B_Paste.gbp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]
2026-10-03 devlog 10
    [clicker-print-plate.3mf, keycap_next.stl, keycap_previous.stl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]
2026-10-16 clarify that the estimate excludes pcb coupons
